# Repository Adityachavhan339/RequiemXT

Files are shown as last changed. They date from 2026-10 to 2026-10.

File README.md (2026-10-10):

# RequiemXT 🎮
RequiemXT is Custom Wired USB Controller.

The controller has:

- 2 Hall-effect joystick modules
- 14 digital buttons
- USB-C wired connection
- RP2040-Zero as the main controller

Schematic Image:
Schematic

PCB Image:
PCB6

## Project Status

Firmware In Progress, Controller Frame Design Will Start Soon

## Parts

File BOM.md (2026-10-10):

# RequiemXT – bill of materials

<!-- Generated by Half Life from project cmuuuymwq0at301smfi1160jm. Edits here are overwritten on the next sync. -->
<!-- Generated: 2026-10-10T15:03:16.653Z -->

> [!NOTE]
> This parts list is mirrored from [Half Life](https://halflife.hackclub.com). Editing it here will not change the platform's copy, and the next sync overwrites this file.

| Week | Tier | Parts funding |
| --- | --- | --- |
| Week 1 | Tier 1 | $30.00 |

| Part | What it's for | Qty | Unit | Total | Vendor |
| --- | --- | --- | --- | --- | --- |
| [Waveshare RP2040-Zero Raspberry Pi MCU With Pre Soldered Header](https://sharvielectronics.com/product/waveshare-rp2040-zero-raspberry-pi-mcu-with-pre-soldered-header/) | Main Controller | 1 | $5.66 | $5.66 | [Sharvi Electronics](https://sharvielectronics.com/product/waveshare-rp2040-zero-raspberry-pi-mcu-with-pre-soldered-header/) |
| [Electronic Spices 6 X 6 X 5mm Blue Color Touch Transient Horn Type Push Button Switch Pack of 20pcs](https://amzn.in/d/009M5XzV) | Controller Buttons | 1 | $1.00 | $1.00 | [Amazon](https://amzn.in/d/009M5XzV) |
| [LCD Digital Display Soldering Iron With 5 Extra Bits (with LCD Display Iron 5 Tips)](https://amzn.in/d/0bvpLAGu) | For Soldering | 1 | $6.80 | $6.80 | [Amazon](https://amzn.in/d/0bvpLAGu) |
| [Jumper Wire Female From Female (40 pcs)](https://amzn.in/d/00hSkNVG) | For Connecting Buttons And Joysticks To Controller | 1 | $1.54 | $1.54 | [Amazon](https://amzn.in/d/00hSkNVG) |
| [Robocraze PS2 Joystick Module Dual Axis Analog Sensor Push Button Switch](https://amzn.in/d/06HGvXh2) | Can't Make A Controller Without Joystick | 2 | $2.87 | $5.74 | [Amazon](https://amzn.in/d/06HGvXh2) |
| **Parts subtotal** | — | — | — | **$20.74** | — |
| **Tax & shipping** | — | — | — | **$2.06** | — |
| **Total** | — | — | — | **$22.80** | — |

$7.20 left of the tier's funding.

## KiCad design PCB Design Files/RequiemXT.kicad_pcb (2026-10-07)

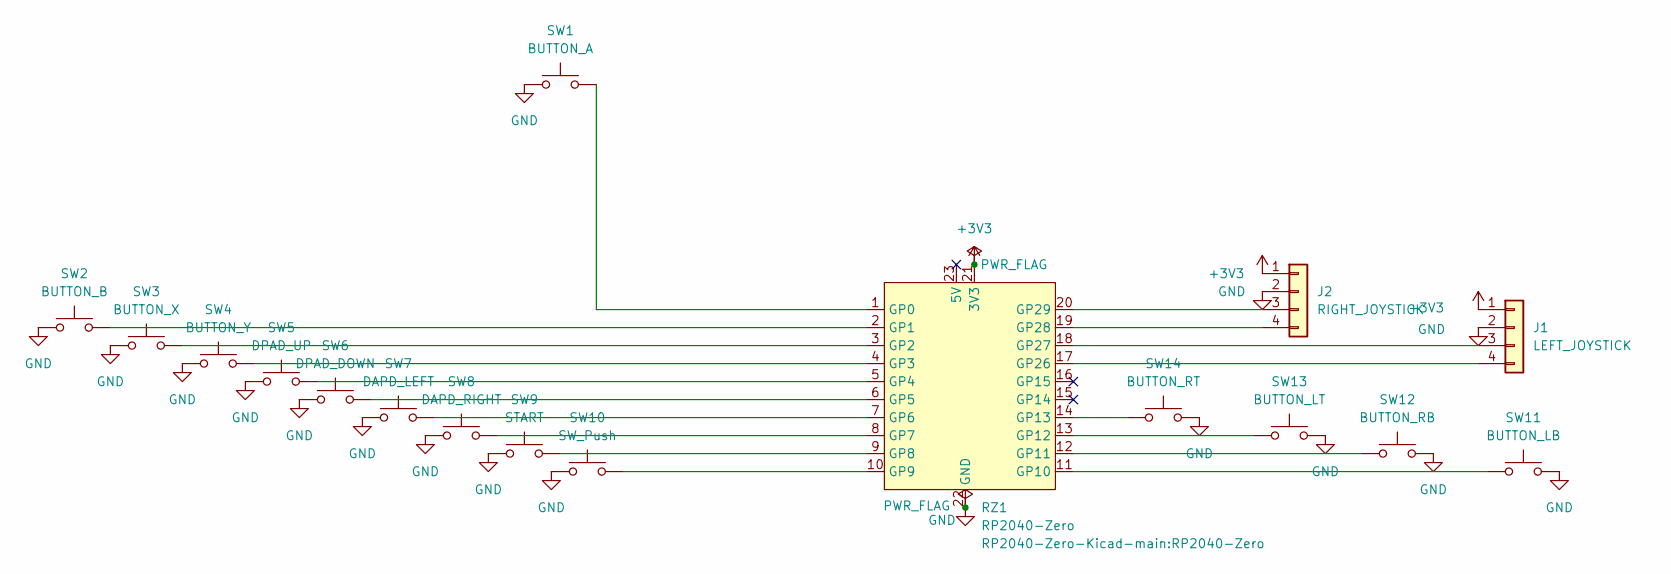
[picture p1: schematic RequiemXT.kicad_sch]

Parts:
J1: LEFT_JOYSTICK; PinHeader_1x04_P2.54mm_Vertical
J2: RIGHT_JOYSTICK; PinHeader_1x04_P2.54mm_Vertical
RZ1: RP2040-Zero
SW1: BUTTON_A; SW_NKK_GW12LJP
SW2: BUTTON_B; SW_PUSH_6mm
SW3: BUTTON_X; SW_PUSH_6mm
SW4: BUTTON_Y; SW_PUSH_6mm
SW5: DPAD_UP; SW_PUSH_6mm
SW6: DPAD_DOWN; SW_PUSH_6mm
SW7: DAPD_LEFT; SW_PUSH_6mm
SW8: DAPD_RIGHT; SW_PUSH_6mm
SW9: START; SW_PUSH_6mm
SW10: SW_Push; SW_PUSH_6mm
SW11: BUTTON_LB; SW_PUSH_6mm
SW12: BUTTON_RB; SW_PUSH_6mm
SW13: BUTTON_LT; SW_PUSH_6mm
SW14: BUTTON_RT; SW_PUSH_6mm

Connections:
+3V3: J1.1, J2.1, RZ1.21 (3V3)
GND: J1.2, J2.2, RZ1.22 (GND), SW1.1, SW2.1, SW3.1, SW4.1, SW5.1, SW6.1, SW7.1, SW8.1, SW9.1, SW10.1, SW11.2, SW12.2, SW13.2, SW14.2
unnamed: J1.3, RZ1.18 (GP27)
unnamed: J1.4, RZ1.17 (GP26)
unnamed: J2.3, RZ1.20 (GP29)
unnamed: J2.4, RZ1.19 (GP28)
unnamed: RZ1.1 (GP0), SW1.2
unnamed: RZ1.2 (GP1), SW2.2
unnamed: RZ1.3 (GP2), SW3.2
unnamed: RZ1.4 (GP3), SW4.2
unnamed: RZ1.5 (GP4), SW5.2
unnamed: RZ1.6 (GP5), SW6.2
unnamed: RZ1.7 (GP6), SW7.2
unnamed: RZ1.8 (GP7), SW8.2
unnamed: RZ1.9 (GP8), SW9.2
unnamed: RZ1.10 (GP9), SW10.2
unnamed: RZ1.11 (GP10), SW11.1
unnamed: RZ1.12 (GP11), SW12.1
unnamed: RZ1.13 (GP12), SW13.1
unnamed: RZ1.14 (GP13), SW14.1

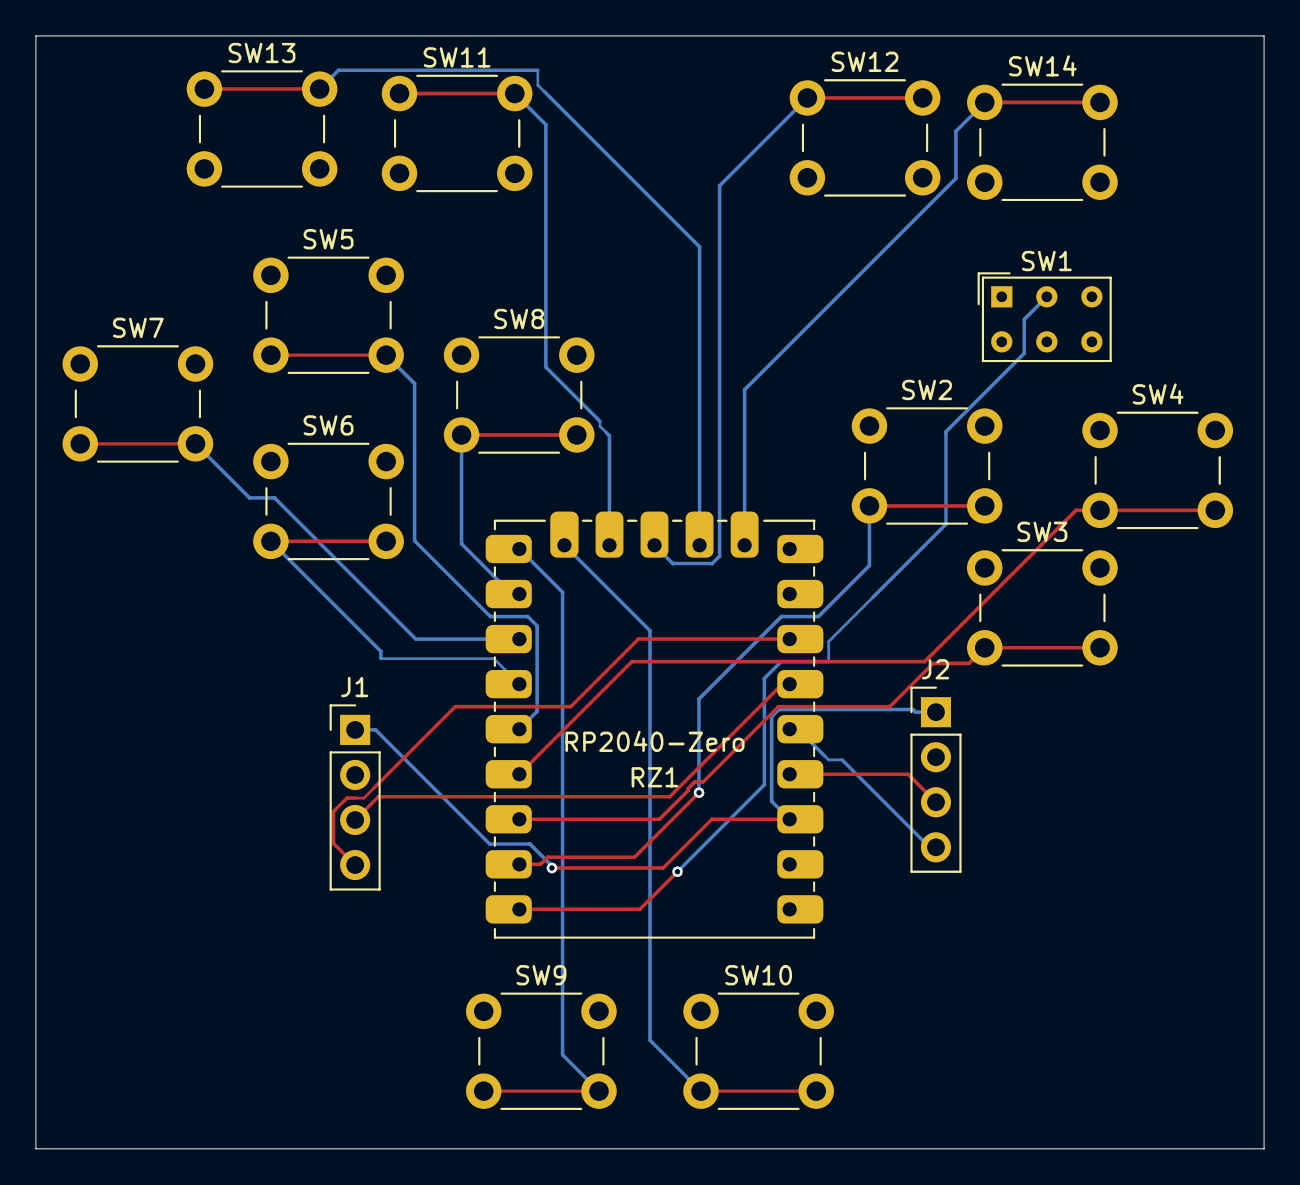
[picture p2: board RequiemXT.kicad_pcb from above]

Board: 2 copper layers, 69.2 x 62.8 mm, 17 parts (0 on the bottom side), 20 nets.

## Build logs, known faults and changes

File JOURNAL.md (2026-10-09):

# RequiemXT – devlog

<!-- Generated by Half Life from project cmuuuymwq0at301smfi1160jm. Edits here are overwritten on the next sync. -->
<!-- Generated: 2026-10-07T12:07:07.525Z -->

> [!NOTE]
> This devlog is mirrored from [Half Life](https://halflife.hackclub.com). Editing it here will not change the platform's copy, and the next sync overwrites this file.

> RequiemXT is a custom wired USB game controller with dual Hall-effect joysticks, 14 buttons, and an SSD1306 OLED display.

| Week | Tier | Hours logged | Entries |
| --- | --- | --- | --- |
| Week 1 | Tier 1 | 10h | 3 |

## Contents

1. [2026-10-05 – October 5th: Requiem XT Gaming Controller](#2026-10-05-october-5th-requiem-xt-gaming-controller)
2. [2026-10-06 – October 6: ADC Pin Trouble](#2026-10-06-october-6-adc-pin-trouble)
3. [2026-10-07 – In Today's Session i started with opening PCB editor it was okay little complicated but i started positioning all buttons in a controller layout which was quite quick i quickly added all buttons in po](#2026-10-07-in-todays-session-i-started-with-opening-pcb-edit)

## Design

### 2026-10-05 – October 5th: Requiem XT Gaming Controller

**2.5h**

October 5th: Requiem XT Gaming Controller

So I Opened KiCad Created A New Project , as i have spent decent amount of time understanding how to add buttons and connect wires.

For starting i added Raspberry Pi Pico in Schematic editor and started adding all required buttons,
i need to add 14 Buttons instead of standard 12 like every controller because i am using buttons instead of analog triggers.

14 Buttons I added In This Session:
1) BUTTON_A        5) DPAD_UP           9) START
2) BUTTON_B        6) DPAD_DOWN    10) SELECT
3) BUTTON_X        7) DPAD_LEFT
4) BUTTON_Y        8) DPAD_RIGHT

11) BUTTON_RT  (Can't call them triggers any more)
12) BUTTON_RB
13) BUTTON_LT
14) BUTTON_LB

Schematic

After adding buttons i started adding joystick, after finding out how to add that,
i added GND and +3V3 on Conn_01x04 Connector then connected the bottom 2 pins to GPIO26 / ADC0 and GPIO27 / ADC1 pins.

The hardest part was making sure wires don’t overlap so it took quite a bit of time understanding how to place everything without making a mess.

After i ran electrical rule checker all my excitement was gone 22 errors!
what a great start 🤡.

Electrical Rule Check 1

But who would have thought just adding few x on unused pins will lower errors to 13.

Electrical Rule Check 2

Main Thing As complete beginner was understanding how the whole KiCad works if i haven’t spend a full day learning before half life started,
this it would have taken whole day.

Time Spent This Session: 2.5 Hour

### 2026-10-06 – October 6: ADC Pin Trouble

**5h**

October 6: ADC Pin Trouble

I Started today's session with solving remaining Electrical rule errors and adding the last joystick but i just found out joystick requires 2 ADC pins to connect but Raspberry Pi Pico only exposes 3 of those pins.
I did bit of researching and the only options i found are either i have to use analog multiplexer IC or external I2C/SPI ADC chip which i don’t want because that will make things a lot complicated and budget might also break.

Schematic1

So I Started to look for a different daughterboard And found Waveshare RP2040 Zero which is 100% Compatible and exposes all 4 ADC Pins.
I found the required files to add in KiCad, Created new project and imported the New Board.

Adding Buttons again was quite easy only problem was wires as this board was little smaller than PI Pico

Schematic2

I added all buttons only 2 joysticks left, i ran Electrical Rule Checker for fun and as expected 13 errors WTH!

ERC1

I added joysticks, after adding both joysticks and some cross mark on unused pins errors dropped to 8 but i didn’t felt happy because i have no idea what else is left as i already added all buttons and 2 joysticks.

Schematic3

ERC2

After doing a strategic discussion with ChatGPT i found out i need to add GND and 3v3 on board so i followed instructions and slowly started solving errors and it worked most errors got solved, only a warning about footprint left so i started solving the footprint issue and it all happened because i added footprint folder in symbol library.

ERC3

I  assigned all footprints fun part was buttons they all only needed BUTTON_SWITCH_THT:SW_PUSH-6mm as footprint it was done fairly quickly

FOOTPRINT

What I learnt in this session: Read KiCad Import instructions carefully a small word change can waste 20 mins finding out why footprint is not working.

Time Spent This Session: 5 Hours

### 2026-10-07 – In Today's Session i started with opening PCB editor it was okay little complicated but i started positioning all buttons in a controller layout which was quite quick i quickly added all buttons in po

**2.5h**

In Today's Session i started with opening PCB editor it was okay little complicated but i started positioning all buttons in a controller layout which was quite quick i quickly added all buttons in position.

PCB1

After Using Edge Cut To make Boundary I finally started the hardest part of today PCB routing  the first few were easy but after i routed the 4 of joysticks all remaining got overlapped it didn't worked.

PCB2

PCB3

so i started researching and kept trying but it didn't worked i routed all buttons but i just couldn't solve the overlapping issue  it was mess

PCB4

So after unknown amount of time i found out about a auto routing plugin called Freerouting
i installed it and ran the plugin and got bunch of errors about board setup then after researching issue i finnaly found solution , it was the design rules constraints clearance and width after i changed it to 0.15mm from 0.20mm almost all errors were gone only 2 buttons were unrouted and i had no idea which ones so i started digging through documentation and asking chatgpt.

PCB5

After Looking through for a long time i finally found the issue all i needed to do was re running the Freerouting after i updated design rules and it worked finally it worked no errors and 0 Unrouted buttons.

PCB6

After All Hassle I finally exported Gerber Output files.

Output GerBer

Time Spent This Session: 2.5 Hours

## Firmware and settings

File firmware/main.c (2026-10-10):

#include <stdio.h>
#include "pico/stdlib.h"
#include "hardware/adc.h"

//Button Mappings
#define BTN_A         0
#define BTN_B         1
#define BTN_Y         2
#define BTN_X         3
#define DPAD_UP       4
#define DPAD_DOWN     5
#define DPAD_LEFT     6
#define DPAD_RIGHT    7
#define START_BTN     8
#define SELECT_BTN    9
#define BTN_LB        10
#define BTN_RB        11
#define BTN_LT        12
#define BTN_RT        13

//Joysticks Inputs (ADC)
#define JOY_LEFT_X    26
#define JOY_LEFT_Y    27
#define JOY_RIGHT_X   28
#define JOY_RIGHT_Y   29

void setup_hardware() {
    const uint buttons[] = {BTN_A, BTN_B, BTN_Y, BTN_X, DPAD_UP, DPAD_DOWN, 
                            DPAD_LEFT, DPAD_RIGHT, START_BTN, SELECT_BTN, 
                            BTN_LB, BTN_RB, BTN_LT, BTN_RT};
    for (int i = 0; i < 14; i++) {
        gpio_init(buttons[i]);
        gpio_set_dir(buttons[i], GPIO_IN);
        gpio_pull_up(buttons[i]);
    }

    adc_init();
    adc_gpio_init(JOY_LEFT_X);
    adc_gpio_init(JOY_LEFT_Y);
    adc_gpio_init(JOY_RIGHT_X);
    adc_gpio_init(JOY_RIGHT_Y);
}

int main() {
    stdio_init_all();
    setup_hardware();

    while (true) {
        tight_loop_contents();
    }
}

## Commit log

2026-10-07 Add initial PCB design configuration file
2026-10-07 Added Remaining PCB Design Files
    [RequiemXT.kicad_pcb, RequiemXT.kicad_sch]
2026-10-10 Add main.c for hardware setup and button mapping
2026-10-10 RP2040 KiCad Import Zip
2026-10-11 Create BOM.csv with item details and costs
    Added a Bill of Materials (BOM) with item details including cost and links.
2026-10-11 Include tax and shipping in BOM.csv
    Added tax and shipping cost for the whole order.
2026-10-11 Clean up BOM.csv by removing duplicates
    Removed duplicate entries and fixed links in BOM.csv.
2026-10-16 Create PCB file directory
2026-10-16 Added PCB Design Files
2026-10-16 Added Gerber Zip
2026-10-17 Revise BOM with new links and total cost
    Updated links and adjusted total cost for BOM.
2026-10-17 Added Zip file to add RP2040 In KiCad
2026-10-17 Create Gerber Files Directory
2026-10-17 Added Gerber Files
